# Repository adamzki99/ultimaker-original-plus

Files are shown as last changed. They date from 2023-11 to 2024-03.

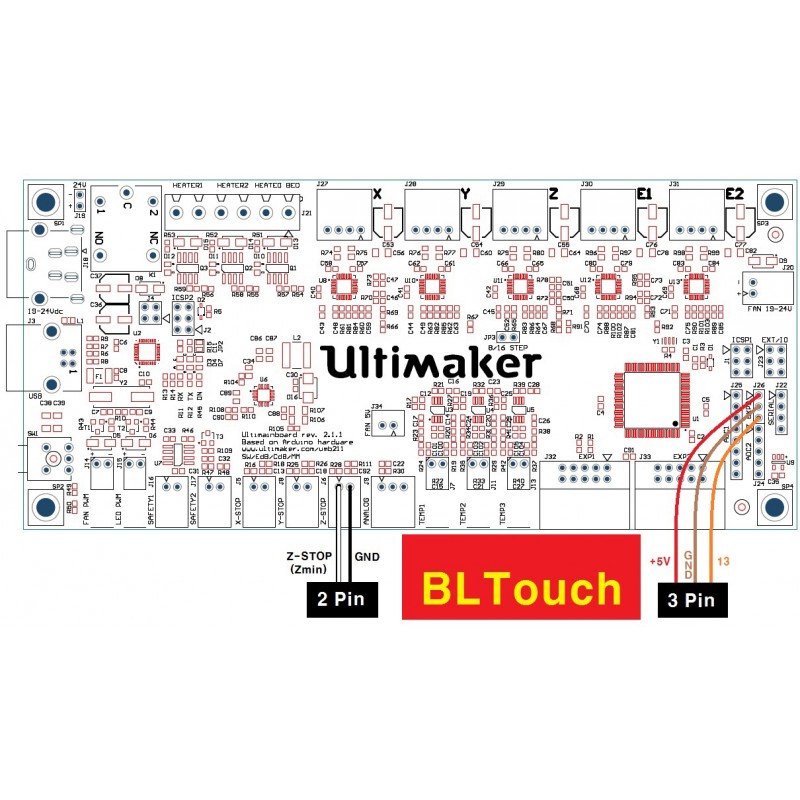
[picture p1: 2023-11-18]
images/bl-touch-with-ultimaker-v2.jpg

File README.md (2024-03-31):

# UltiMaker Original+
Collection of information regarding my UltiMaker Original+

## History

The printer was purchased in November 2023 in Stockholm, Sweden, for SEK 1000.

Realizing that UltiMaker no longer maintains the Firmware and that the latest release is labeled "DEV," I wanted to find an alternative firmware. 
Klipper came to mind, and after following the official documentation, the printer was up and running.

Currently, I am printing parts and tuning the machine.

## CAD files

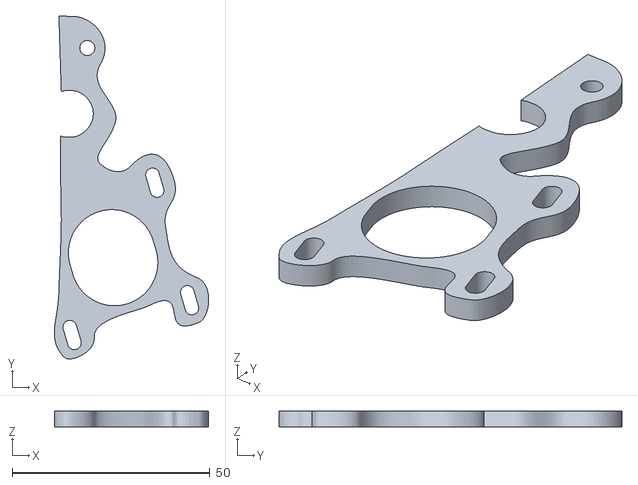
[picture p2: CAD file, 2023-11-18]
printed-parts/extruder/feeder_suspension_middlepiece.stl
39.1 x 86.8 x 4.00

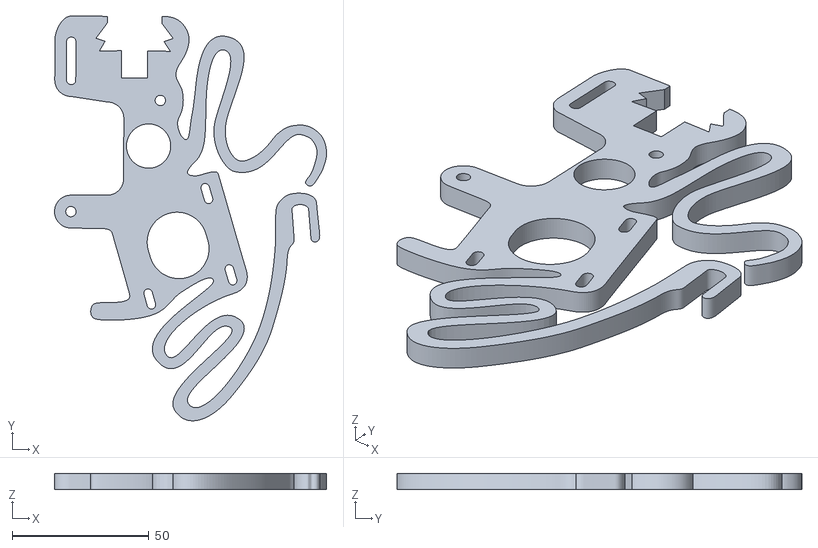
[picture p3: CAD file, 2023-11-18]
printed-parts/extruder/feeder_suspension.stl
99.5 x 148.0 x 6.00

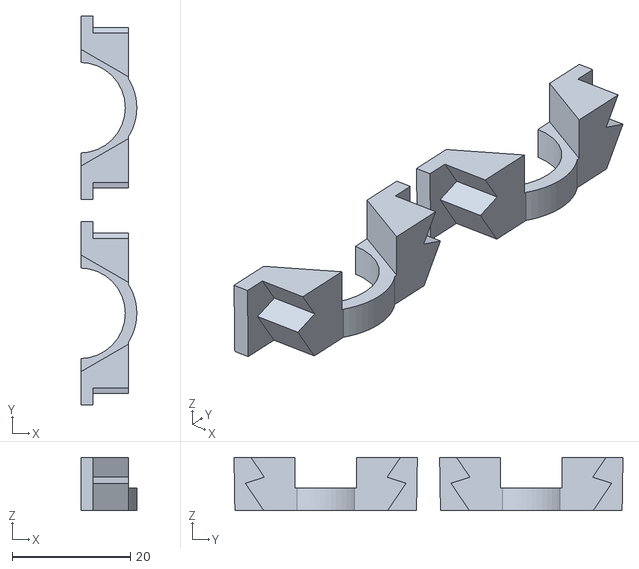
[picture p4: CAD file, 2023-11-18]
printed-parts/extruder/feeder_suspension_coupling_holder.stl
9.41 x 65.7 x 9.01

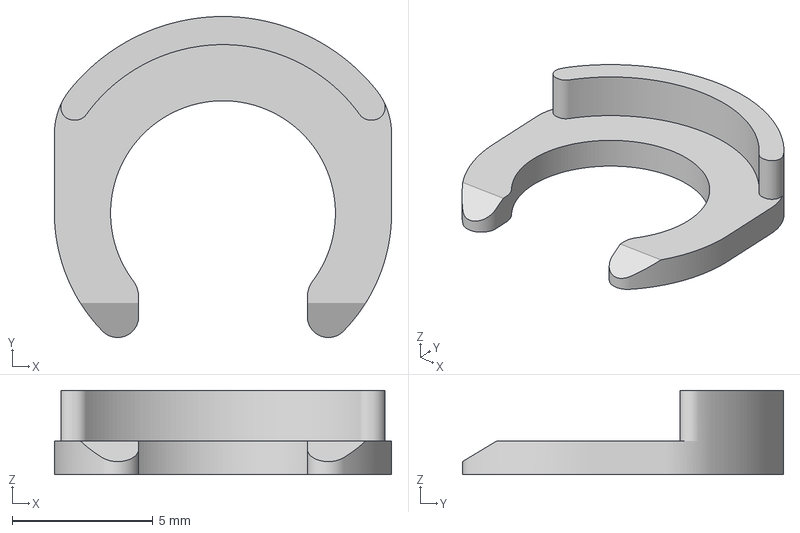
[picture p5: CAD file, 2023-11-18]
printed-parts/extruder/Bowden Clip.3mf
12.0 x 11.4 x 3.00 mm

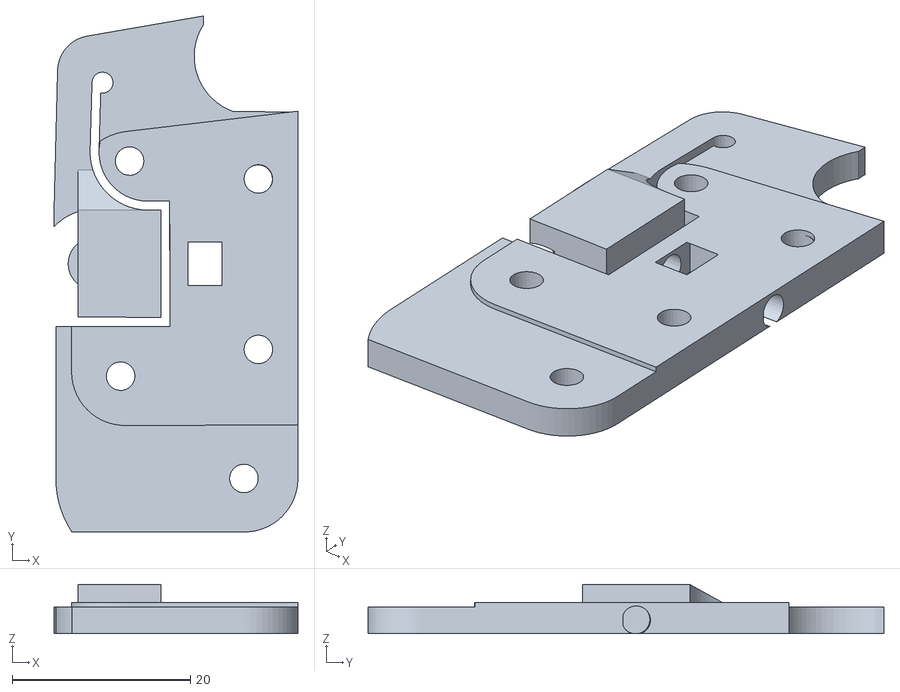
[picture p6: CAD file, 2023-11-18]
printed-parts/extruder/extruder_clamp_Centre1.stl
27.3 x 57.8 x 5.50

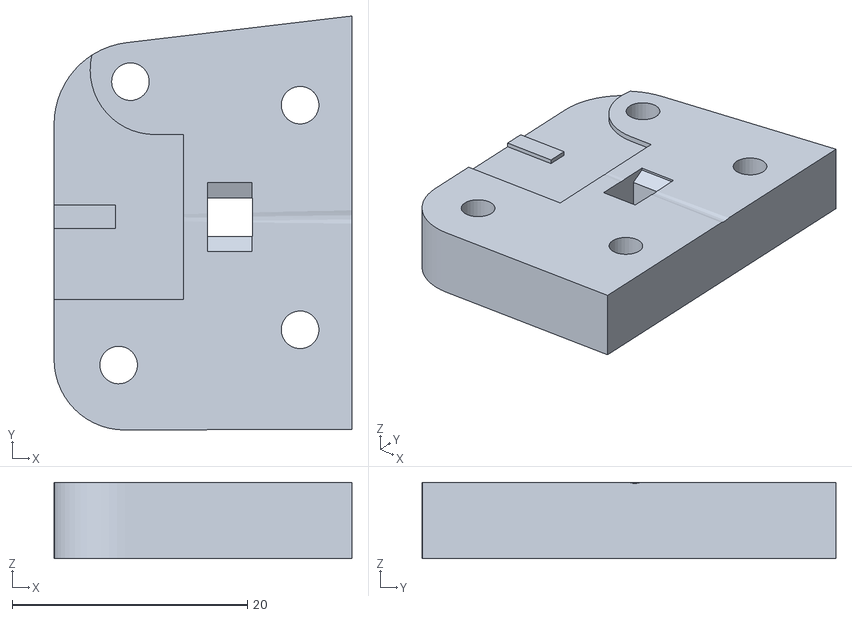
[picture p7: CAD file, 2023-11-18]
printed-parts/extruder/extruder_clamp_LHS1.stl
25.3 x 35.2 x 6.50

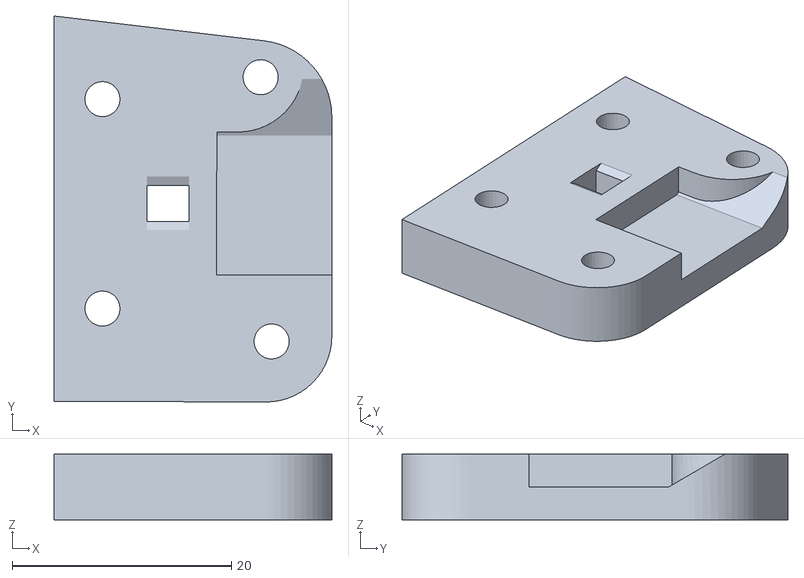
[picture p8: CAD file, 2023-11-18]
printed-parts/extruder/extruder_clamp_RHS1.stl
25.3 x 35.2 x 6.00

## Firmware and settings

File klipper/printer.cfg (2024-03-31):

# This file contains pin mappings for the stock Sovol SV06
# To use this config, during "make menuconfig" select the
# STM32F103 with a "28KiB bootloader" and serial (on USART1 PA10/PA9) communication.
# Also, since it is using the GD32F103, please select Disable SWD at startup
#
# Flash this firmware by copying "out/klipper.bin" to a SD card and
# turning on the printer with the card inserted. The firmware
# filename must end in ".bin" and must not match the last filename
# that was flashed.
#
# See docs/Config_Reference.md for a description of parameters.
#
# This configuration has been altered to work with an UltiMaker Original+ 
# with modifications. Double-check the configuration before applying it 
# to your machine.

[include fluidd.cfg]
[include macros.cfg]

[skew_correction]

[mcu]
serial: /dev/serial/by-id/usb-1a86_USB_Serial-if00-port0
restart_method: command

[temperature_sensor mainboard]
sensor_type: temperature_mcu
min_temp: 0
max_temp: 100

[virtual_sdcard]
path: /home/ultimaker/printer_data/gcodes
on_error_gcode: CANCEL_PRINT

[printer]
kinematics: cartesian
max_velocity: 200
max_accel: 4000
max_z_velocity: 25
max_z_accel: 30

[stepper_x]
step_pin: PC2
dir_pin: PB9
enable_pin: !PC3
microsteps: 256
rotation_distance: 40.0
endstop_pin: tmc2209_stepper_x:virtual_endstop
position_endstop: -9.0
position_min: -9.0
position_max: 205.0
homing_speed: 20.0
homing_retract_dist: 0

[tmc2209 stepper_x]
uart_pin: PC1
run_current: 0.900
stealthchop_threshold: 999999
interpolate: True
sense_resistor: 0.150
uart_address: 3
driver_SGTHRS: 55
diag_pin: PA5

[stepper_y]
step_pin: PB8
dir_pin: !PB7
enable_pin: !PC3
microsteps: 256
rotation_distance: 40
endstop_pin: tmc2209_stepper_y:virtual_endstop
position_endstop: -8.5
position_min: -8.5
position_max: 205
homing_speed: 20
homing_retract_dist: 0

[tmc2209 stepper_y]
uart_pin: PC0
run_current: 0.900
stealthchop_threshold: 999999
interpolate: True
sense_resistor: 0.150
uart_address: 3
driver_SGTHRS: 45
diag_pin: PA6

[stepper_z]
step_pin: PB6
dir_pin: PB5
enable_pin: !PC3
microsteps: 256
rotation_distance: 8.0
endstop_pin: ^!PA7
#position_endstop: 0.15
position_min: -1.0
position_max: 200.0
homing_speed: 20.0
homing_retract_dist: 10.0

[tmc2209 stepper_z]
uart_pin: PA15
run_current: 1.000
stealthchop_threshold: 0
interpolate: True
sense_resistor: 0.150
uart_address: 3
diag_pin: PA7

[extruder]
max_extrude_only_distance: 800.0
step_pin: PB4
dir_pin: !PB3
enable_pin: !PC3
microsteps: 32
rotation_distance: 6.95
nozzle_diameter: 0.400
filament_diameter: 2.850
heater_pin: PA1
sensor_type: EPCOS 100K B57560G104F
sensor_pin: PC5
#control: pid
#pid_kd: 86.991
#pid_kp: 21.479
#pid_ki: 1.326
min_temp: 0
max_temp: 275
pressure_advance: 0.30

[tmc2209 extruder]
uart_pin: PC14
run_current: 0.550
stealthchop_threshold: 0
interpolate: True
sense_resistor: 0.150
uart_address: 3

[heater_bed]
heater_pin: PA2
sensor_type: EPCOS 100K B57560G104F
sensor_pin: PC4
#control: pid
#pid_kp: 64.440
#pid_ki: 0.773
#pid_kd: 1343.571
min_temp: 0
max_temp: 100

[bed_screws]
screw1: 0.0, 5.0 
screw1_name: front left screw
screw2: 205.0, 5.0
screw2_name: front right screw
screw3: 90.0, 205.0
screw3_name: rear middle screw

[fan]
pin: PA0

[mcu rpi]
serial: /tmp/klipper_host_mcu

[temperature_sensor raspberry_pi]
sensor_type: temperature_host
min_temp: 10
max_temp: 100

[adxl345]
cs_pin: rpi:None

[resonance_tester]
accel_chip: adxl345
probe_points: 102.5, 102.5, 100

#*# <---------------------- SAVE_CONFIG ---------------------->
#*# DO NOT EDIT THIS BLOCK OR BELOW. The contents are auto-generated.
#*#
#*# [extruder]
#*# control = pid
#*# pid_kp = 22.386
#*# pid_ki = 0.750
#*# pid_kd = 167.057
#*#
#*# [heater_bed]
#*# control = pid
#*# pid_kp = 66.482
#*# pid_ki = 1.355
#*# pid_kd = 815.232
#*#
#*# [stepper_z]
#*# position_endstop = 0.575
#*#
#*# [input_shaper]
#*# shaper_type_x = mzv
#*# shaper_freq_x = 38.4
#*# shaper_type_y = ei
#*# shaper_freq_y = 46.4
#*#
#*# [skew_correction calilantern_skew_profile]
#*# xy_skew = -0.0005020498436448471
#*# xz_skew = 0.0
#*# yz_skew = 0.0

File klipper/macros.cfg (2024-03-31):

#-------------------------------------------------------------------------------#
#-------------------------------- Custom Macros --------------------------------#
#-------------------------------------------------------------------------------#
#-------------------------------------------------------------------------------#

[gcode_macro CENTER_PRINT_HEAD]
gcode:
    G28 ;home all axis
    G1 Z5
    G1 X102.5 Y102.5 F6000
    M400

[gcode_macro LEVEL_BED]
    # https://www.klipper3d.org/Manual_Level.html
gcode:
    G28 ;home all axis
    BED_SCREWS_ADJUST ;start leveling the bed

[gcode_macro REMOVE_MATERIAL]
gcode:
    {% set EXTRUDER_TEMP = params.EXTRUDER_TEMP|default(210)|float %}
    
    G90 ;absolute coordinates
    G28 X0 Y0 ;home gantry

    G1 X102.5 Y10.0 ;move the nozzle to the front
    
    M109 S{EXTRUDER_TEMP} ;wait for nozzle to reach temp

    G92 E0 ;reset extruder
    G1 E-5 F100 ;retract 5 mm slowly
    G1 E-800 F1500 ;retract 800 mm

    M400 ;wait for previous moves

[gcode_macro INSERT_MATERIAL]
gcode:
    {% set EXTRUDER_TEMP = params.EXTRUDER_TEMP|default(220)|float %}
    G90 ;use absolute coordinates
    G92 E0 ;reset extruder

    M109 S{EXTRUDER_TEMP} ;wait for nozzle to reach temp
    
    G1 E650 F1500 ;extrude 650 mm, fast, to the hotend
    G1 E50 F100 ;extrude 100 mm slowly
    
    M400 ;wait for previous moves
    G1 E-10 F1500 ;perform a small, fast, retract to limit ooze
    G92 E0 ;reset extruder

[gcode_macro START_PRINT]
gcode:
    {% set BED_TEMP = params.BED_TEMP|default(60)|float %}
    {% set EXTRUDER_TEMP = params.EXTRUDER_TEMP|default(200)|float %}

    SKEW_PROFILE LOAD=calilantern_skew_profile
   
    G21 ;metric values
    G90 ;absolute positioning
    M82 ;set extruder to absolute mode
    M107 ;start with the fan off
    G28 X0 Y0 ;move X/Y to min endstops
    G28 Z0 ;move Z to min endstops
    #G1 X102.5 Y2.5 Z15.0 F9000 ;move the platform down 15mm and bring printhead forward

    M400 ;wait for previous moves
    M140 S{BED_TEMP} ;start bed heating
    M190 S{BED_TEMP} ;wait unitl bed has reached its target
    M104 S{EXTRUDER_TEMP} ;start nozzle heating

    M400 ;wait for previous moves
    G92 E0 ;zero the extruded length
    G1 X102.5 Y202.0 Z0.3 F5000.0 ;move to start position
    M109 S{EXTRUDER_TEMP} ;wait for nozzle to reach temp before proceeding
    G92 E0 ;zero the extruded length again
    G1 X202.0 Y202.0 Z0.3 F1500.0 E5 ;draw the first line
    G1 X202.0 Y2.5 Z0.3 F1500.0 E15 ;draw the second line
    G92 E0 ;zero the extruded length
    G1 Z2.0 F3000 ;move z up little to prevent scratching of Heat Bed
    G1 X202.0 Y105.0 Z0.3 F5000.0 ;move over to prevent blob squish
    
    M400 ;wait for previous moves

[gcode_macro END_PRINT]
gcode:
    M400 ;wait for previous moves
    M104 S0 ;extruder heater off
    M140 S0 ;heated bed heater off

    G91 ;relative positioning
    G1 E-1 F300  ;retract the filament a bit before lifting the nozzle, to release some of the pressure
    G1 Z+0.5 E-5 X-20 Y-20 F9000 ;move Z up a bit and retract filament even more
    G90 ;absolute positioning
    G1 X202.5 Y202.5 Z200 ;move the print-head out of the way
    
    M84 ;steppers off

    SET_SKEW CLEAR=1
    
[gcode_macro CANCEL_PRINT]
gcode:
    M400 ;wait for previous moves
    G28 X0.0 Y0.0 ;home gantry so the print-head is out of the way

    M400 ;wait for previous moves
    G91 ;relative positioning
    G1 E-1 F9000 ;retract the filament a bit before lifting the nozzle to release some of the pressure
    G1 E-5 F300 ;retract the filament even more
    M106 S76 ;set fan speed to 30% to prevent heat soaking

    M400 ;wait for previous moves
    M84 ;steppers off

#-------------------------------------------------------------------------------#
#------------------------------- Klipper Defined -------------------------------#
#-- https://github.com/Klipper3d/klipper/blob/master/config/sample-macros.cfg --#
#-------------------------------------------------------------------------------#

######################################################################
# Override M117 command with rawparams
######################################################################

# The macro below will override the default M117 command to echo the message.
#
# It uses the rawparams pseudo-variable that contains the full unparsed
# parameters that was passed to the M117 command.
#
# As this can include comments, we are trimming the text when a `;` or `#` is
# found, and escaping any existing `"`

[gcode_macro M117]
rename_existing: M117.1
gcode:
  {% if rawparams %}
    {% set escaped_msg = rawparams.split(';', 1)[0].split('\x23', 1)[0]|replace('"', '\\"') %}
    SET_DISPLAY_TEXT MSG="{escaped_msg}"
    RESPOND TYPE=command MSG="{escaped_msg}"
  {% else %}
    SET_DISPLAY_TEXT
  {% endif %}

# SDCard 'looping' (aka Marlin M808 commands) support
#
# Support SDCard looping
[sdcard_loop]

# 'Marlin' style M808 compatibility macro for SDCard looping
[gcode_macro M808]
gcode:
    {% if params.K is not defined and params.L is defined %}SDCARD_LOOP_BEGIN COUNT={params.L|int}{% endif %}
    {% if params.K is not defined and params.L is not defined %}SDCARD_LOOP_END{% endif %}
    {% if params.K is defined and params.L is not defined %}SDCARD_LOOP_DESIST{% endif %}

# Cancel object (aka Marlin/RRF M486 commands) support
#
# Enable object exclusion
[exclude_object]

[gcode_macro M486]
gcode:
  # Parameters known to M486 are as follows:
  #   [C<flag>] Cancel the current object
  #   [P<index>] Cancel the object with the given index
  #   [S<index>] Set the index of the current object.
  #       If the object with the given index has been canceled, this will cause
  #       the firmware to skip to the next object. The value -1 is used to
  #       indicate something that isn’t an object and shouldn’t be skipped.
  #   [T<count>] Reset the state and set the number of objects
  #   [U<index>] Un-cancel the object with the given index. This command will be
  #       ignored if the object has already been skipped

  {% if 'exclude_object' not in printer %}
    {action_raise_error("[exclude_object] is not enabled")}
  {% endif %}

  {% if 'T' in params %}
    EXCLUDE_OBJECT RESET=1

    {% for i in range(params.T | int) %}
      EXCLUDE_OBJECT_DEFINE NAME={i}
    {% endfor %}
  {% endif %}

  {% if 'C' in params %}
    EXCLUDE_OBJECT CURRENT=1
  {% endif %}

  {% if 'P' in params %}
    EXCLUDE_OBJECT NAME={params.P}
  {% endif %}

  {% if 'S' in params %}
    {% if params.S == '-1' %}
      {% if printer.exclude_object.current_object %}
        EXCLUDE_OBJECT_END NAME={printer.exclude_object.current_object}
      {% endif %}
    {% else %}
      EXCLUDE_OBJECT_START NAME={params.S}
    {% endif %}
  {% endif %}

  {% if 'U' in params %}
    EXCLUDE_OBJECT RESET=1 NAME={params.U}
  {% endif %}

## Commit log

2023-11-18 Upload of initial conifg
    [macros.cfg, printer.cfg]
2023-11-18 Add mainboard schematic
2023-11-18 Add printed parts for extruder upgrade
    [Bowden Clip.3mf, extruder_clamp_Centre1.stl, extruder_clamp_LHS1.stl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]
2024-03-31 Mainboard upgrade
    [printer.cfg]
